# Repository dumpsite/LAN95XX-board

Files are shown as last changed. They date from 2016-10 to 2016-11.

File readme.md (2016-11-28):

SMSC LAN95XX adapter board
==========================

This board serves as a carrier for the famous LAN95XX 
(LAN9512, LAN9513 or LAN9514) USB to fast Ethernet controller.

All the (high) frequency-, power- and decoupling stuff is done
on the board, while the most interesting pins are routed to the
outside edges. There the pitch is the usual 2.54mm (0.1") and
easily accessible for any further projects.

The board features an onboard eeprom (type "93C56 or 93C66") in cheap
SO8 package and implements a 25 MHz 5032 SMD crystal circuit.
(For cheaper HC49* versions there was no space...)
The smallest component is 0603, but most of them are replaceable with some 0805...

All is done (and works!) with two active design layers only!
A theoretical third layer is "emulated" by connecting some edge-pins together.
So it needs not be produced with the PCB itself...
The traces are scaled a bit thinner to compensate spreading during design transfer
to copper. All package footprints are using longer pin pads.
The primary IC (LAN95XX) QFN package footprint is extended by an 3.2mm inner
bonding hole, allowing backside soldering and solder bridging the two layers.

All this allows fully DIY capability and "etching at home".
VIAs can be drilled using 0.2mm or 0.3mm drill.
Side-to-side bonding can be done using stripped AWG30 wire wrapping wire.

The minimal essential size is "33mm x 33mm" using castellations or
"36mm x 36mm" using full pin headers.
Including the whole PCB area having the board nicely centered, its
dimensions are "50mm x 50mm" .

All the content is open and freely usable in non commercial applications.
It would be very kind to mention me in your projects and ask me first if you plan commercial use...

by Stephan Baerwolf (stephan@matrixstorm.com), Schwansee 2016

(who is not bearing any responsibility or guarantee of any kind for his projects)

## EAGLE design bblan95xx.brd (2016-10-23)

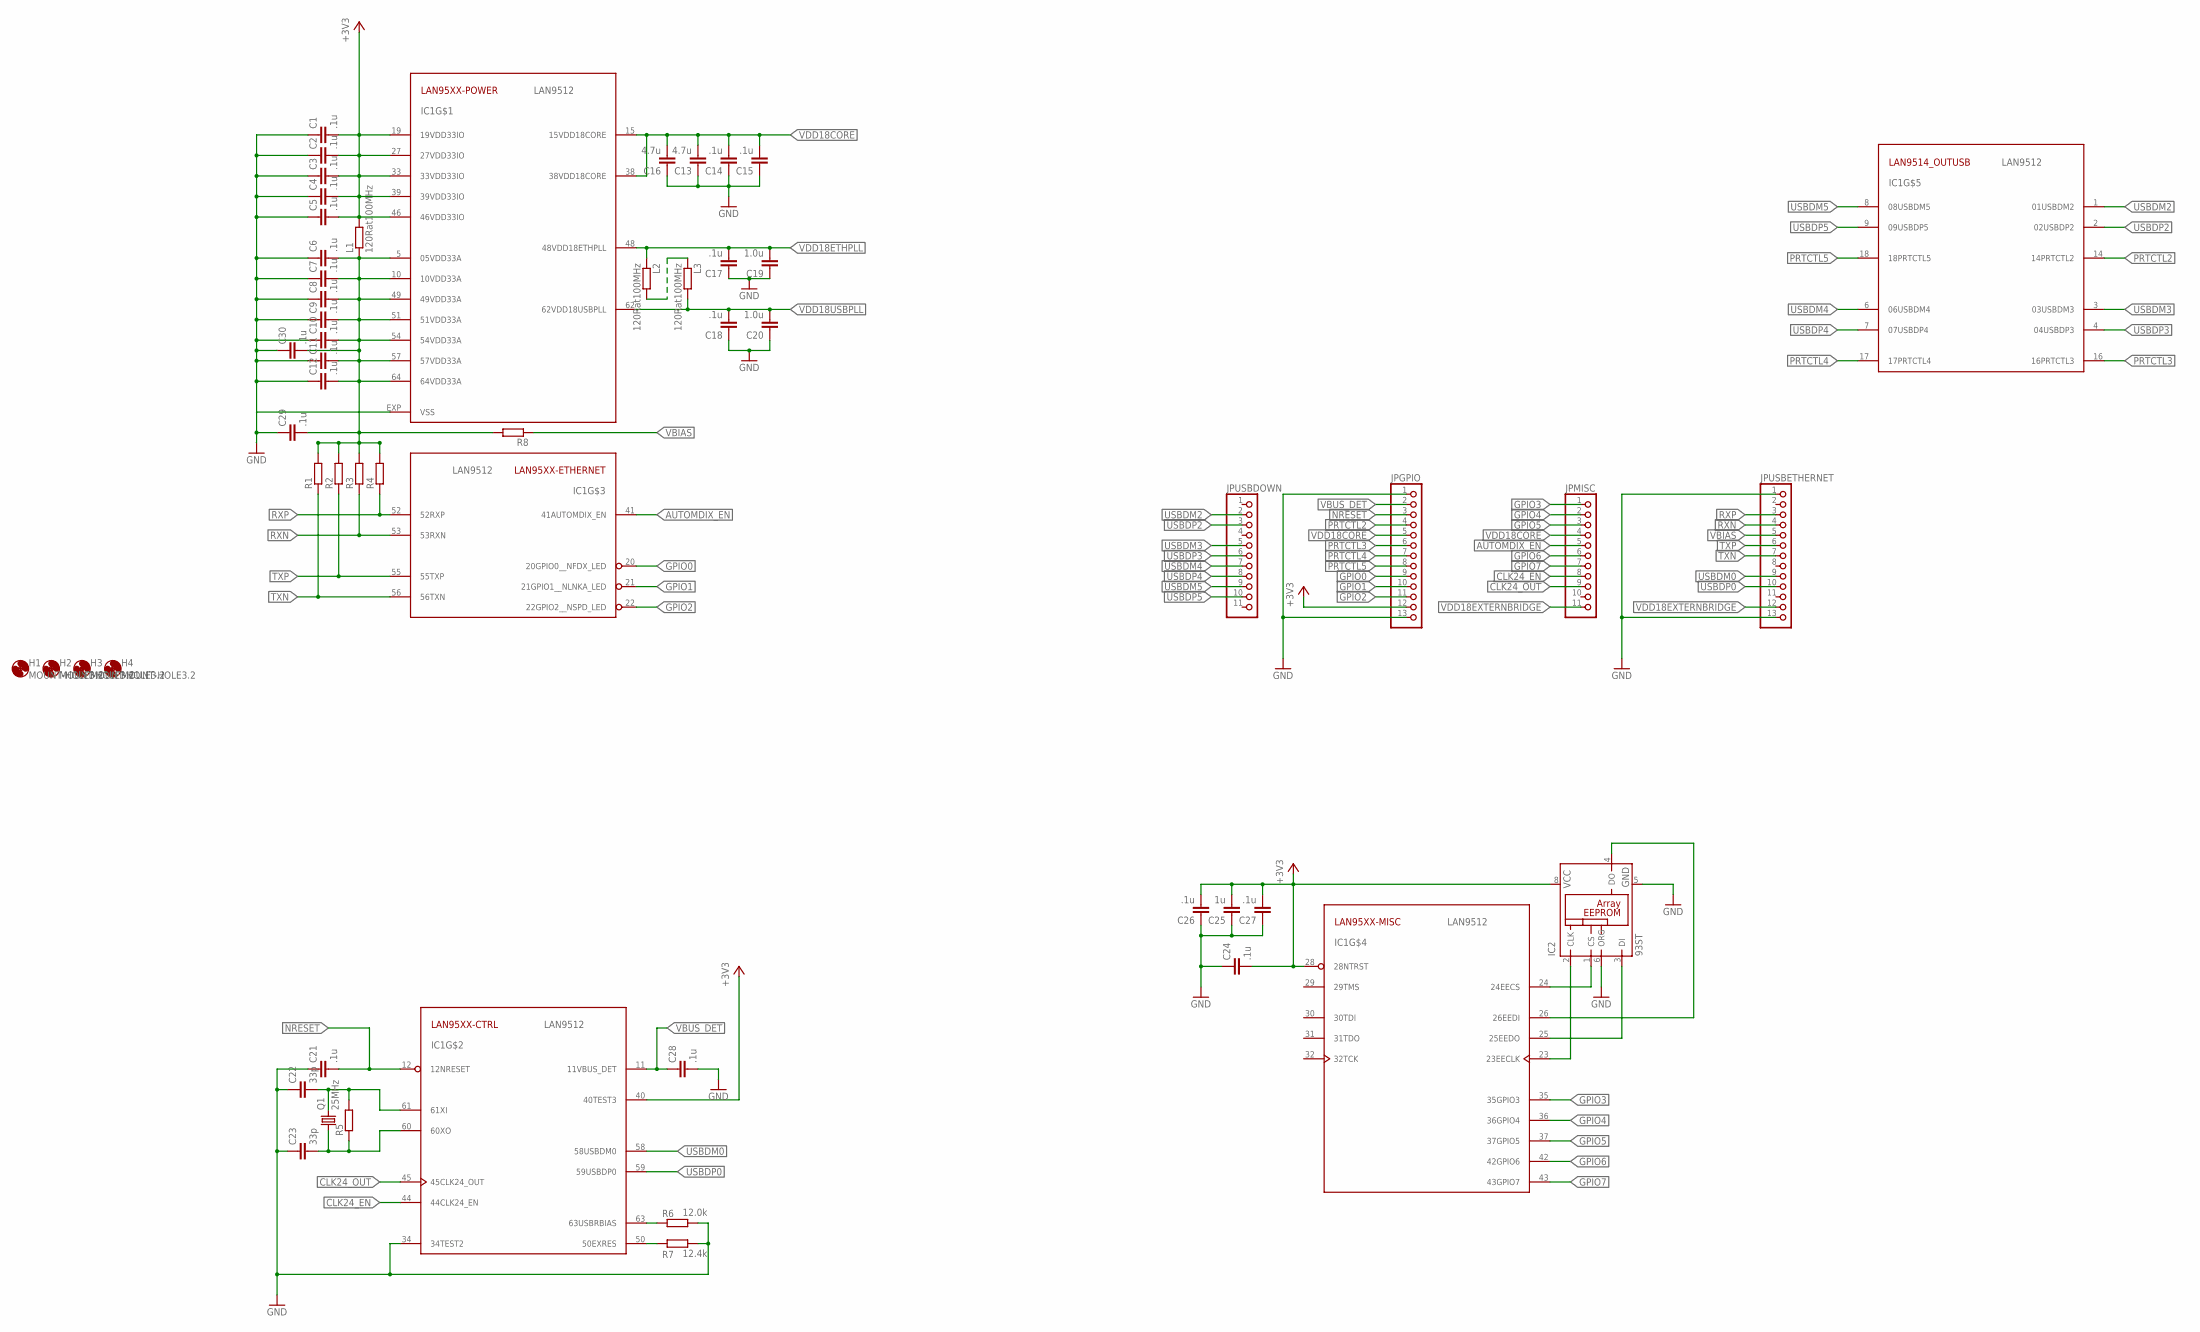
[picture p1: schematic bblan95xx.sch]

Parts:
C1, C2, C3, C4, C5, C6, C7, C8, C12, C26, C27: .1u; C0805K
C9, C10, C11, C14, C15, C17, C18, C21, C24, C28, C29, C30: .1u; C0603K
C13, C16: 4.7u; C0805K
C19, C20: 1.0u; C0805K
C22, C23: 33p; C0603K
C25: 1u; C0805K
H1, H2, H3, H4: MOUNT-HOLE3.2; 3,2
IC1: LAN9512; QFN64-9X9-EXTRALONG
IC2: 93ST; SO-08
JPGPIO: PINHD-1X13; 1X13
JPMISC: PINHD-1X11; 1X11
JPUSBDOWN: PINHD-1X11; 1X11
JPUSBETHERNET: PINHD-1X13; 1X13
L1, L2, L3: 120Rat100MHz; R0805
Q1: 25MHz; CRYSTAL-SMD-5X3
R1, R2, R3, R4, R5: R-EU_R0603; R0603
R6: 12.0k; R0603
R7: 12.4k; R0603
R8: R-EU_R0402; R0402

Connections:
+3V3: C1.2, C2.2, C3.2, C4.2, C5.2, C24.2, C25.2, C26.2, C27.2, IC1.19 (19VDD33IO), IC1.27 (27VDD33IO), IC1.28 (28NTRST), IC1.33 (33VDD33IO), IC1.39 (39VDD33IO), IC1.40 (40TEST3), IC1.46 (46VDD33IO), IC2.8 (VCC), JPGPIO.12, L1.2
AUTOMDIX_EN: IC1.41 (41AUTOMDIX_EN), JPMISC.5
CLK24_EN: IC1.44 (44CLK24_EN), JPMISC.8
CLK24_OUT: IC1.45 (45CLK24_OUT), JPMISC.9
EECLK: IC1.23 (23EECLK), IC2.2 (CLK)
EECS: IC1.24 (24EECS), IC2.1 (CS)
EEDI: IC1.26 (26EEDI), IC2.4 (DO)
EEDO: IC1.25 (25EEDO), IC2.3 (DI)
GND: C1.1, C2.1, C3.1, C4.1, C5.1, C6.1, C7.1, C8.1, C9.1, C10.1, C11.1, C12.1, C13.1, C14.1, C15.1, C16.1, C17.1, C18.1, C19.1, C20.1, C21.1, C22.1, C23.1, C24.1, C25.1, C26.1, C27.1, C28.2, C29.1, C30.1, IC1.34 (34TEST2), IC1.EXP (VSS), IC2.5 (GND), IC2.6 (ORG), JPGPIO.1, JPGPIO.13, JPUSBETHERNET.1, JPUSBETHERNET.13, R6.2, R7.2
GPIO0: IC1.20 (20GPIO0__NFDX_LED), JPGPIO.9
GPIO1: IC1.21 (21GPIO1__NLNKA_LED), JPGPIO.10
GPIO2: IC1.22 (22GPIO2__NSPD_LED), JPGPIO.11
GPIO3: IC1.35 (35GPIO3), JPMISC.1
GPIO4: IC1.36 (36GPIO4), JPMISC.2
GPIO5: IC1.37 (37GPIO5), JPMISC.3
GPIO6: IC1.42 (42GPIO6), JPMISC.6
GPIO7: IC1.43 (43GPIO7), JPMISC.7
unnamed: IC1.63 (63USBRBIAS), R6.1
unnamed: IC1.50 (50EXRES), R7.1
NRESET: C21.2, IC1.12 (12NRESET), JPGPIO.3
PRTCTL2: IC1.14 (14PRTCTL2), JPGPIO.4
PRTCTL3: IC1.16 (16PRTCTL3), JPGPIO.6
PRTCTL4: IC1.17 (17PRTCTL4), JPGPIO.7
PRTCTL5: IC1.18 (18PRTCTL5), JPGPIO.8
RXN: IC1.53 (53RXN), JPUSBETHERNET.4, R3.1
RXP: IC1.52 (52RXP), JPUSBETHERNET.3, R4.1
TXN: IC1.56 (56TXN), JPUSBETHERNET.7, R1.1
TXP: IC1.55 (55TXP), JPUSBETHERNET.6, R2.1
USBDM0: IC1.58 (58USBDM0), JPUSBETHERNET.9
USBDM2: IC1.1 (01USBDM2), JPUSBDOWN.2
USBDM3: IC1.3 (03USBDM3), JPUSBDOWN.5
USBDM4: IC1.6 (06USBDM4), JPUSBDOWN.7
USBDM5: IC1.8 (08USBDM5), JPUSBDOWN.9
USBDP0: IC1.59 (59USBDP0), JPUSBETHERNET.10
USBDP2: IC1.2 (02USBDP2), JPUSBDOWN.3
USBDP3: IC1.4 (04USBDP3), JPUSBDOWN.6
USBDP4: IC1.7 (07USBDP4), JPUSBDOWN.8
USBDP5: IC1.9 (09USBDP5), JPUSBDOWN.10
VBIAS: JPUSBETHERNET.5, R8.1
VBUS_DET: C28.1, IC1.11 (11VBUS_DET), JPGPIO.2
VDD18CORE: C13.2, C14.2, C15.2, C16.2, IC1.15 (15VDD18CORE), IC1.38 (38VDD18CORE), JPGPIO.5, JPMISC.4
VDD18ETHPLL: C17.2, C19.2, IC1.48 (48VDD18ETHPLL), L2.1
VDD18EXTERNBRIDGE: JPMISC.11, JPUSBETHERNET.12, L2.2, L3.1
VDD18USBPLL: C18.2, C20.2, IC1.62 (62VDD18USBPLL), L3.2
VDD33A: C6.2, C7.2, C8.2, C9.2, C10.2, C11.2, C12.2, C29.2, C30.2, IC1.5 (05VDD33A), IC1.10 (10VDD33A), IC1.49 (49VDD33A), IC1.51 (51VDD33A), IC1.54 (54VDD33A), IC1.57 (57VDD33A), IC1.64 (64VDD33A), L1.1, R1.2, R2.2, R3.2, R4.2, R8.2
XI: C22.2, IC1.61 (61XI), Q1.3 (2), R5.2
XO: C23.2, IC1.60 (60XO), Q1.1, R5.1

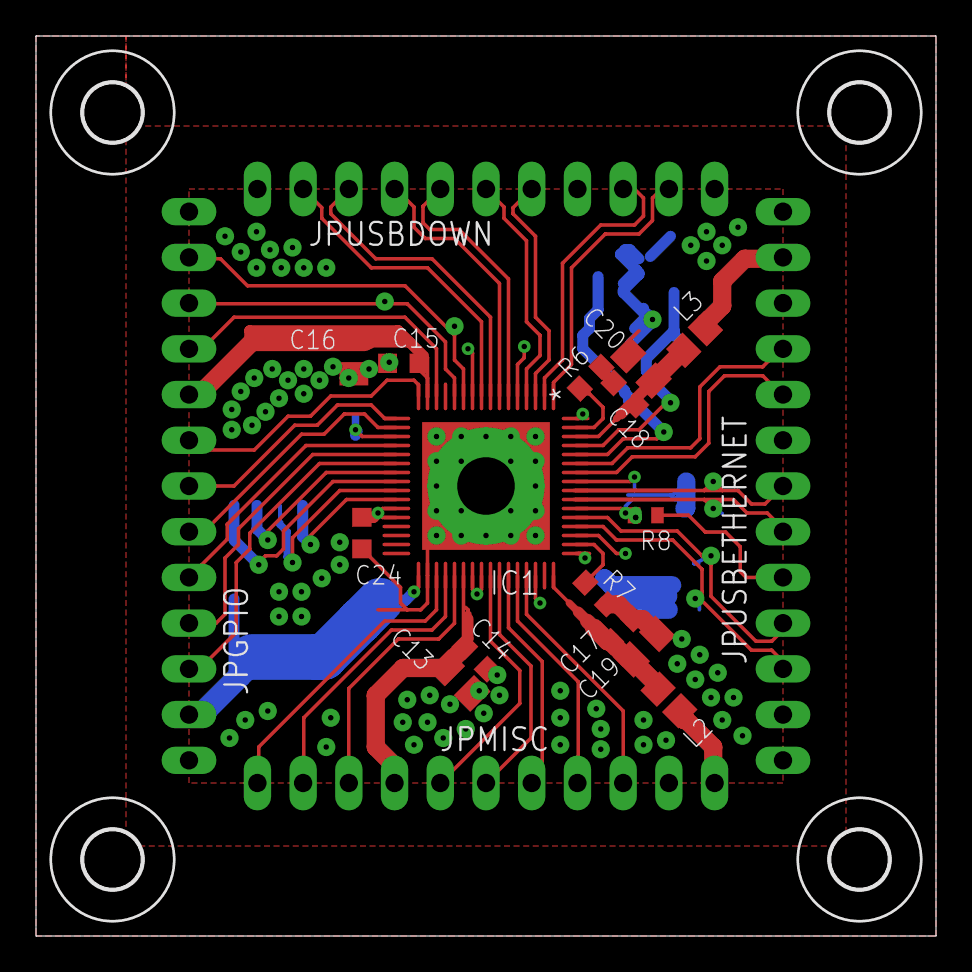
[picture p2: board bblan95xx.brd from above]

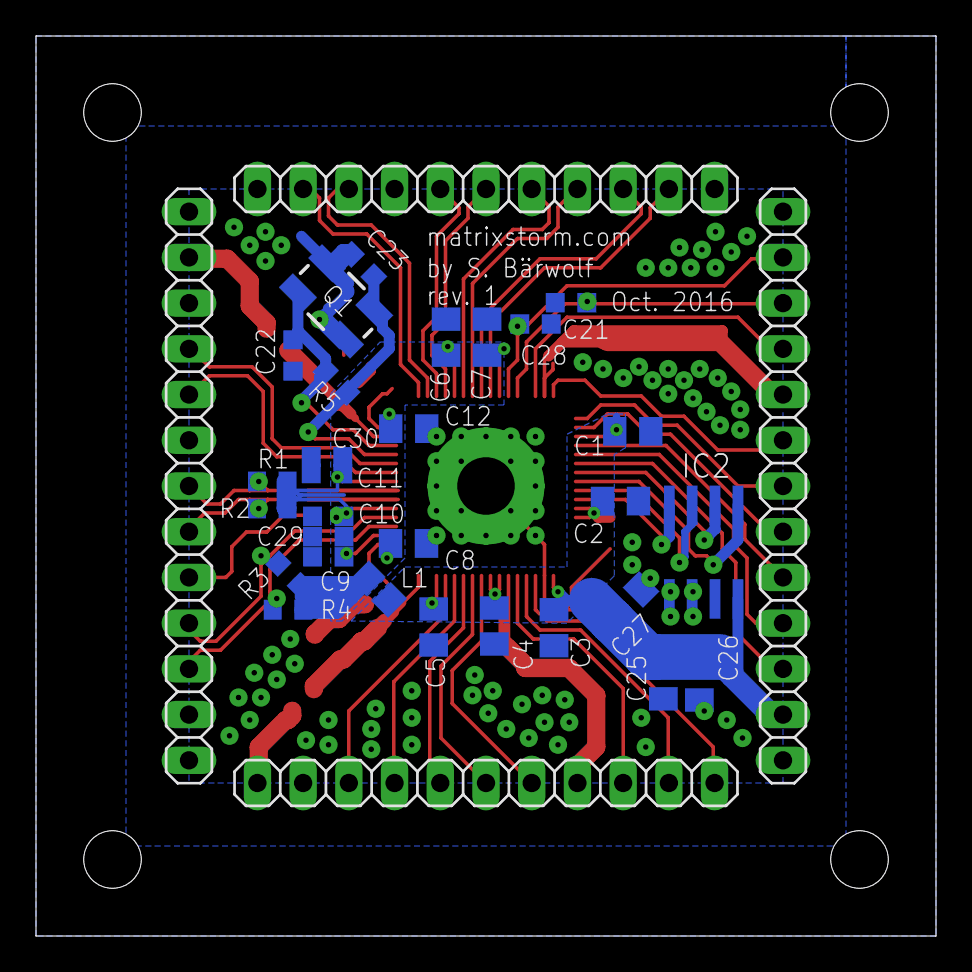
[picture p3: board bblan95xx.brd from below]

Board: 3 copper layers, 50.0 x 50.0 mm, 52 parts (33 on the bottom side), 47 nets.

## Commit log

2016-10-16 starting LAN95xx base board design
    [bblan95xx.brd, bblan95xx.sch]
2016-10-16 shrink primary polygons to final adapter size
    [bblan95xx.brd]
2016-10-16 reroute USB down-port two and crystal cap
    [bblan95xx.brd]
2016-10-16 add extra analog capacitor and route VDD33A to free PIN
    [bblan95xx.brd, bblan95xx.sch]
2016-10-16 add extra 0603 cap and make 0603 to 0805 where possible
    [bblan95xx.brd, bblan95xx.sch]
2016-10-16 add more vias to connect GND planes
    [bblan95xx.brd]
2016-10-16 add also thermal vias to main IC
    [bblan95xx.brd]
2016-10-16 accept all warnings and errors since board is fine
    [bblan95xx.brd]
2016-10-16 mirror pinjumper headers in bottom direction
    [bblan95xx.brd]
2016-10-16 add pseudo c-tool for generating eeprom image during compile
    This patch allows the creation of eeprom-images for the LAN95XX board.
    The current default is for LAN9512 and disables all downstream USB ports.
    So it is for designs just using the ethernet functionality.
    To program data into the eeprom you can use for example ethtool:
    "cat eeprom.bin | ethtool -E ethX magic 0x9500 offset 0x0"
    To change things simply edit the lan95xx_eeprom_configurator.c and
    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
2016-10-16 Fill middle layer "PCBnoRoute" with groundplane
    In case somebody cares to produce a multilayer PCB instead externally connecting
    the Vcore pins, present a nicer middle layer.
    [bblan95xx.brd]
2016-10-19 mirror pinjumper headers try two
    Mirror and rotate JPUSBDOWN and JPMISC
    [bblan95xx.brd]
2016-10-19 add some edge polygons on all copper layers
    [bblan95xx.brd]
2016-10-23 spruce up name layer on top
    [bblan95xx.brd]
2016-10-23 spruce up name layer on bottom
    [bblan95xx.brd]
2016-10-23 finalize gerberizable version 1.2.0
    For silkscreen it is recommended to use additional to "20 Dimension":
    * "51 tDocu" , "25 tNames" and "21 tPlace"
    or for bottom:
    * "52 bDocu" , "26 bNames" and "22 bPlace"
    [bblan95xx.brd, bblan95xx.sch]
2016-10-24 add an example tool to access the lan95xx controller
    This commit implements a small (quick and dirty) demonstration,
    how to access the controller via userspace USB (libusb) to
    do some stuff.
    In this case access the chip ID or statistical data.
    Both can be used to check the quality of the final solder job.
    (Or the ordered chip by that matter...)
    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
2016-11-27 fix: some minor bugs in eeprom around usb-hub configuration
    First make USB-HUB selfpower feature depending on "LAN951X_SELFPOWERED".
    The eeprom header, as also the USB descriptors already are using it.
    (Before this the USB-Hub always indicated to be self-powered...)
    Second: Do not disable overcurrent sensing, since this will violate USB standard when self powering.
    Third: Do not register as (not removable) compound device.
2016-12-04 add eagle library of board footprint for ease of use in further projects
2016-12-10 extend eagle library of board with minimal footprint

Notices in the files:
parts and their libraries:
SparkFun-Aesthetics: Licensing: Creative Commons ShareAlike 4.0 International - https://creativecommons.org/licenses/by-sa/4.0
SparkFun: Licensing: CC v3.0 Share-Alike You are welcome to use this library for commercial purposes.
